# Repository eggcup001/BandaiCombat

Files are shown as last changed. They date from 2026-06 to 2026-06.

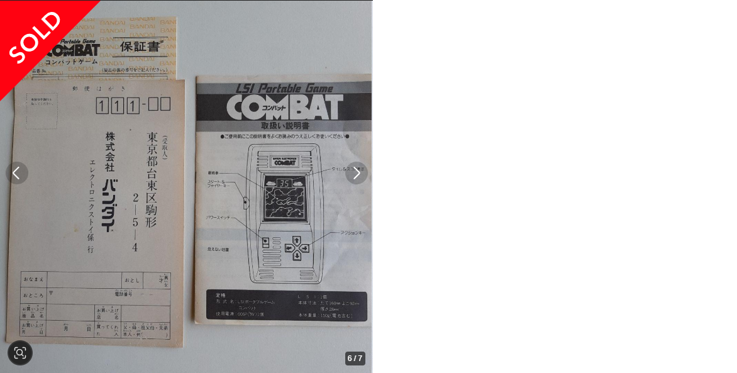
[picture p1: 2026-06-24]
docs/no1/005.png

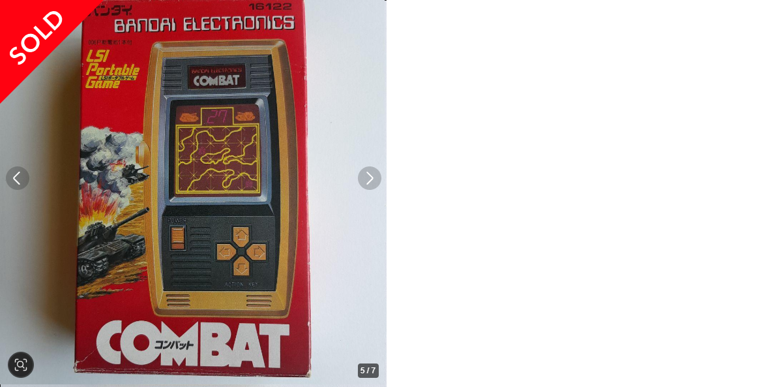
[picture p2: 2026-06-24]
docs/no1/004.png

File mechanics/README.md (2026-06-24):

【ゲーム仕様】
ゲームのカウントは99秒内で自機は10台までで終了。カウントは0から換算され99を超えるとゲームオーバー
5x4のLEDマトリクスに敵機と自機がそれぞれ１台ずつランダムに配置される。また地雷が2～3個配置される。
待機画面は上記で配置された状態で敵機(薄暗い)、自機(明るい)、現在のカウントが表示され、敵機0.5秒間隔くらいで点滅。

Fireボタンでスタート、カウントが1秒ずつ加算される。
上下左右ボタンで自機を移動し、敵の前でFireボタン＋方向で攻撃となる。Fireボタンを押さずに敵と同じマスに入った場合は自機を1台失う。
敵の上下左右又は斜めの、一つ隣に入ると約1秒間隔で敵の攻撃が来る(1回点滅で1攻撃)。
敵の攻撃が連続3回当たると自機を1台失う。自機を移動し隣ではなくなるとヒット回数がリセットされる。

ランダムに配置された地雷の上下左右一つ隣に入ると警告音が鳴る。
地雷を踏むと自機を1台失う。

攻撃が成功した場合は得点が1加算され、次の配置と待機モーションへ移行する。
敵の攻撃や接触、地雷で自機を1台失った場合は、その面の最初の配置にリセットされる(カウンタは増加し続ける)
ゲームオーバーで終了時、得点が表示され、終了。配置は次の面を配置する。スタートで得点を0点へリセットしカウントを0から開始でゲームスタート。

ゲーム進行時はカウントの様な音が鳴り続ける。待機中は無音。自機を失った場合は音が鳴る。
ゲームオーバー時は終了時のメロディーが鳴る。

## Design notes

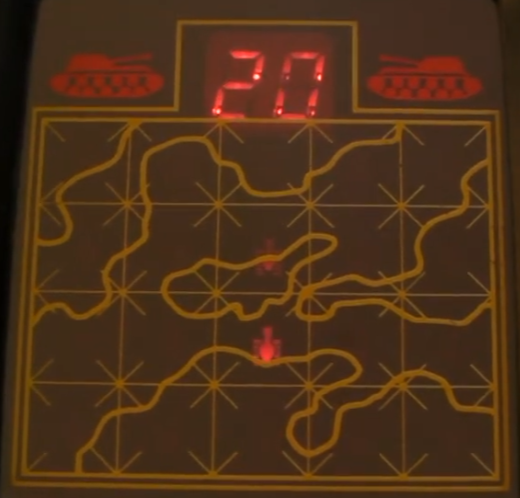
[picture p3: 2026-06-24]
docs/no3/スクリーンショット 2026-06-22 230143.png

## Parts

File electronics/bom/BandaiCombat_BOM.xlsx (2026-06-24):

 | Sourced | Placed | References | Value | Footprint | Quantity
1 |  |  | C2, C3, C4 | 0.1uF | C_Disc_D5.0mm_W2.5mm_P5.00mm | 3
2 |  |  | C1 | 10nF | C_Disc_D5.0mm_W2.5mm_P5.00mm | 1
3 |  |  | C5 | 10uF | CP_Radial_D5.0mm_P2.00mm | 1
4 |  |  | R1, R5 | 10k | R_Axial_DIN0207_L6.3mm_D2.5mm_P7.62mm_Horizontal | 2
5 |  |  | R2, R6 | 1k | R_Axial_DIN0207_L6.3mm_D2.5mm_P7.62mm_Horizontal | 2
6 |  |  | R3 | 2.2k | R_Axial_DIN0207_L6.3mm_D2.5mm_P7.62mm_Horizontal | 1
7 |  |  | R4 | 4.7k | R_Axial_DIN0207_L6.3mm_D2.5mm_P7.62mm_Horizontal | 1
8 |  |  | D00, D01, D02, D03, D10, D11, D12, D13, D20, D21, D22, D23, D30, D31, D32, D33, D40, D41, D42, D43 | LED | LED_D5.0mm | 20
9 |  |  | D4 | 1N4148 | D_DO-35_SOD27_P7.62mm_Horizontal | 1
10 |  |  | U2, U3 | 74HC595 | DIP-16_W7.62mm | 2
11 |  |  | U4, U5 | D168K | D1X8K | 2
12 |  |  | U1 | ATtiny85-20P | DIP-8_W7.62mm | 1
13 |  |  | SW6 | Conn_02x03_Odd_Even | PinHeader_2x03_P2.54mm_Vertical | 1
14 |  |  | Q1, Q2, Q3, Q4, Q5, Q6, Q7 | 2SC1815 | TO-92_Inline | 7
15 |  |  | SW_DOWN1, SW_FIRE1, SW_LEFT1, SW_RIGHT1, SW_UP1 | SW_Push | SW_PUSH_6mm | 5
16 |  |  | RN1, RN2 | 330 | R_Array_Convex_4x0603 | 2
17 |  |  | RN3, RN4 | 4.7k | R_Array_Convex_4x0603 | 2
18 |  |  | 9042_16R1 | Buzzer | MagneticBuzzer_PUI_AT-0927-TT-6-R | 1
19 |  |  | BT1 | Battery | PinHeader_1x02_P2.54mm_Vertical | 1
20 |  |  | RN5 | 100k | R_Array_SIP9 | 1

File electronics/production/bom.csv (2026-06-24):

Designator | Footprint | Quantity | Value | LCSC Part #
9042_16R1 | MagneticBuzzer_PUI_AT-0927-TT-6-R | 1 | Buzzer
BT1 | PinHeader_1x02_P2.54mm_Vertical | 1 | Battery
C1 | C_Disc_D5.0mm_W2.5mm_P5.00mm | 1 | 10nF
C2, C3, C4 | C_Disc_D5.0mm_W2.5mm_P5.00mm | 3 | 0.1uF
C5 | CP_Radial_D5.0mm_P2.00mm | 1 | 10uF
D00, D01, D02, D03, D10, D11, D12, D13, D20, D21, D22, D23, D30, D31, D32, D33, D40, D41, D42, D43 | LED_D5.0mm | 20 | LED
D4 | D_DO-35_SOD27_P7.62mm_Horizontal | 1 | 1N4148
Q1, Q2, Q3, Q4, Q5, Q6, Q7 | TO-92_Inline | 7 | 2SC1815
R1, R5 | R_Axial_DIN0207_L6.3mm_D2.5mm_P7.62mm_Horizontal | 2 | 10k
R2, R6 | R_Axial_DIN0207_L6.3mm_D2.5mm_P7.62mm_Horizontal | 2 | 1k
R3 | R_Axial_DIN0207_L6.3mm_D2.5mm_P7.62mm_Horizontal | 1 | 2.2k
R4 | R_Axial_DIN0207_L6.3mm_D2.5mm_P7.62mm_Horizontal | 1 | 4.7k
RN1, RN2 | R_Array_Convex_4x0603 | 2 | 330
RN3, RN4 | R_Array_Convex_4x0603 | 2 | 4.7k
RN5 | R_Array_SIP9 | 1 | 100k
SW6 | PinHeader_2x03_P2.54mm_Vertical | 1 | Conn_02x03_Odd_Even
SW_DOWN1, SW_FIRE1, SW_LEFT1, SW_RIGHT1, SW_UP1 | SW_PUSH_6mm | 5 | SW_Push
U1 | DIP-8_W7.62mm | 1 | ATtiny85-20P
U2, U3 | DIP-16_W7.62mm | 2 | 74HC595
U4, U5 | D1X8K | 2 | D168K

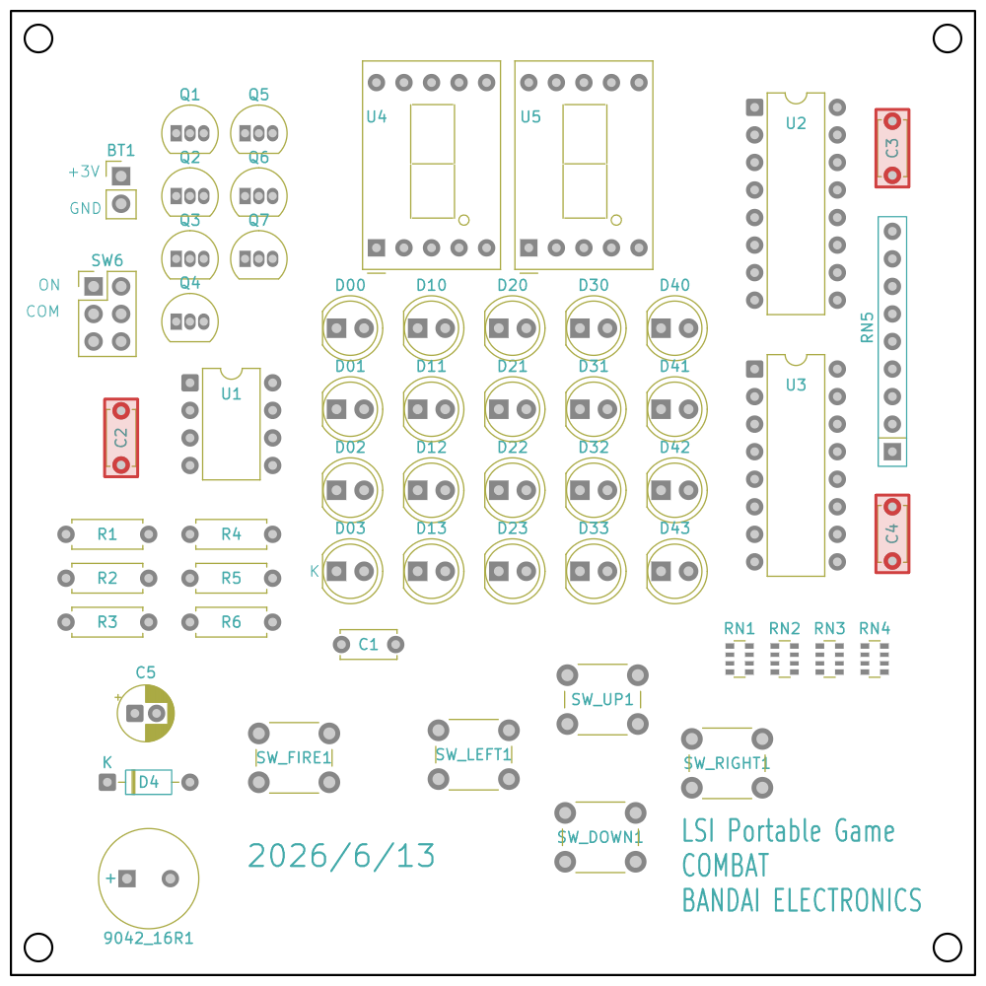
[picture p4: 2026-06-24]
electronics/bom/BandaiCombat.F.png

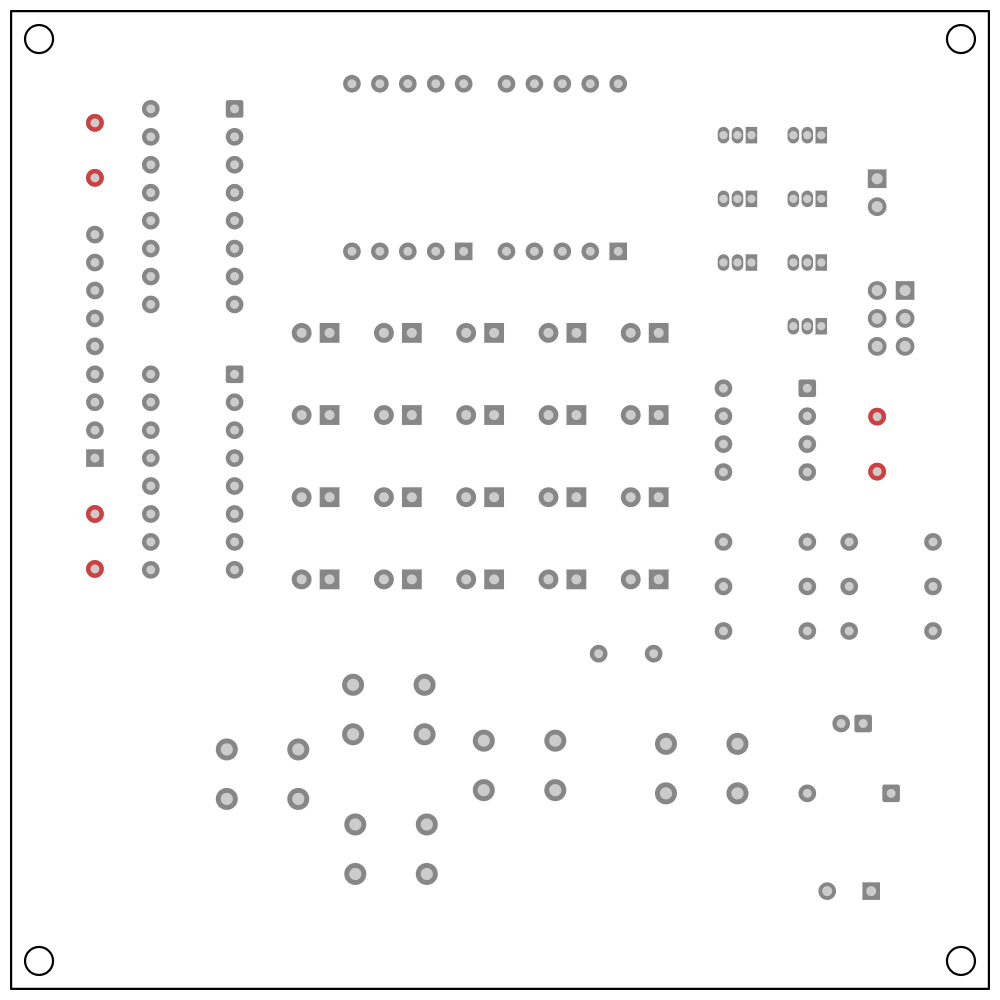
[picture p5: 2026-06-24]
electronics/bom/BandaiCombat.B.png

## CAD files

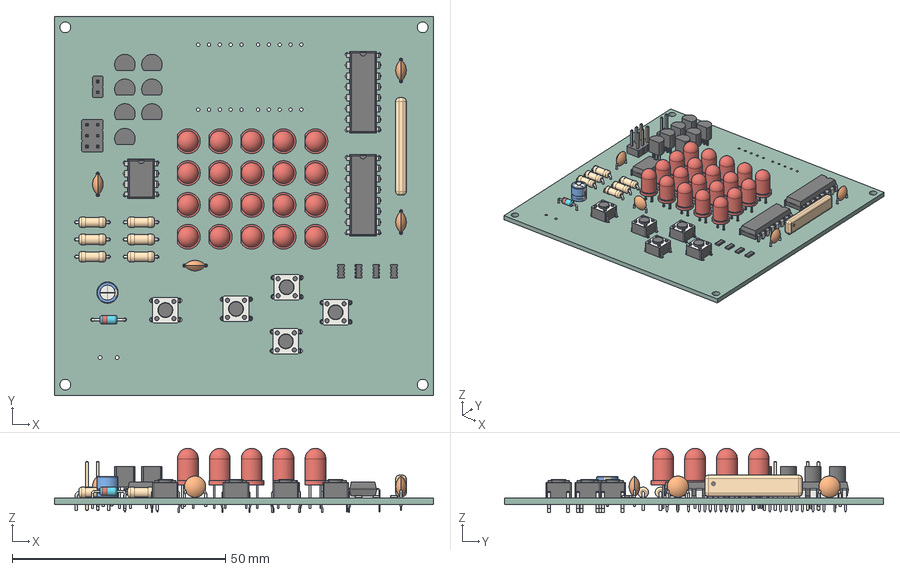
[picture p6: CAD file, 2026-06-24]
electronics/doc/基板2.step
88.9 x 88.9 x 15.1 mm
R_Array_Convex_4x0603 x 4
R_Axial_DIN0207_L6.3mm_D2.5mm_P7.62mm_Horizontal x 6
LED_D5.0mm x 20
SW_PUSH_6mm x 5
TO-92_Inline x 7
C_Disc_D5.0mm_W2.5mm_P5.00mm x 4
D_DO-35_SOD27_P7.62mm_Horizontal
CP_Radial_D5.0mm_P2.00mm
PinHeader_2x03_P2.54mm_Vertical
DIP-8_W7.62mm
R_Array_SIP9
DIP-16_W7.62mm x 2
PinHeader_1x02_P2.54mm_Vertical
BandaiCombat_PCB

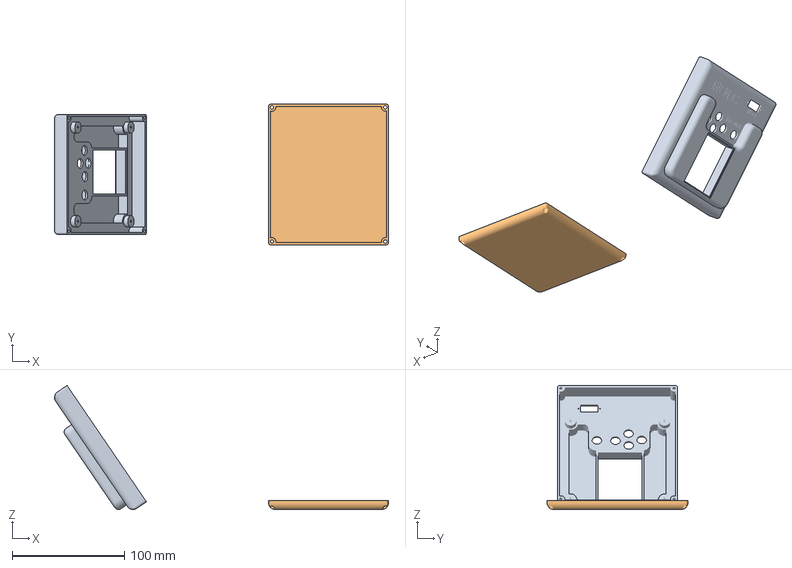
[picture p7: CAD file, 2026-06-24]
mechanics/bambu/combat_box.3mf
298.1 x 125.7 x 110.7 mm
top
bottom

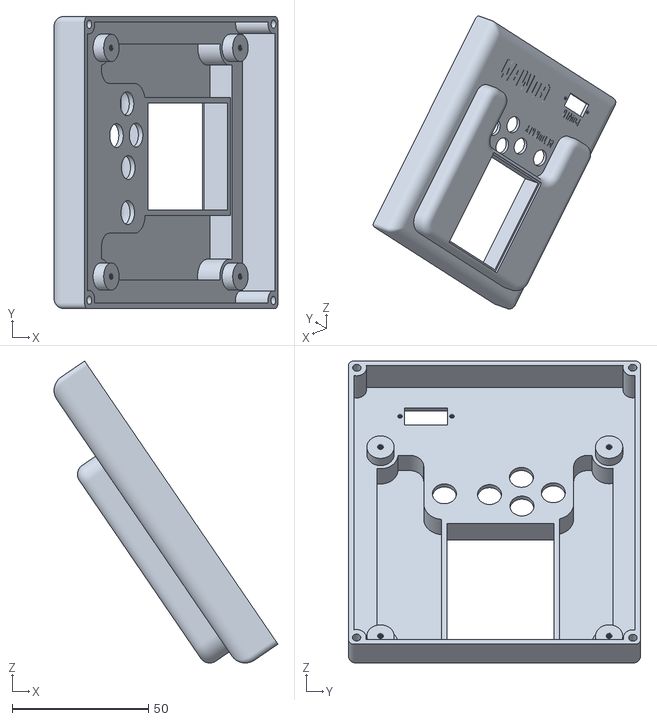
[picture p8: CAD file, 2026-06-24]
mechanics/stl/top.stl
82.1 x 107.1 x 110.7

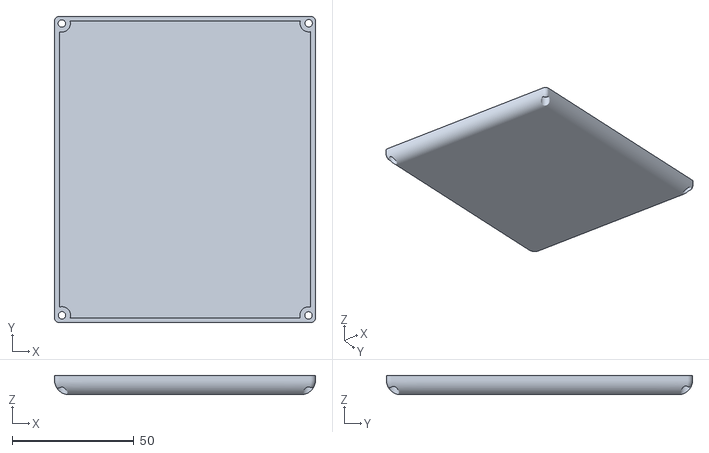
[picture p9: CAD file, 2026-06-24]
mechanics/stl/bottom.stl
107.1 x 125.7 x 8.00

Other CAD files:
mechanics/fusion/combat_box.f3d

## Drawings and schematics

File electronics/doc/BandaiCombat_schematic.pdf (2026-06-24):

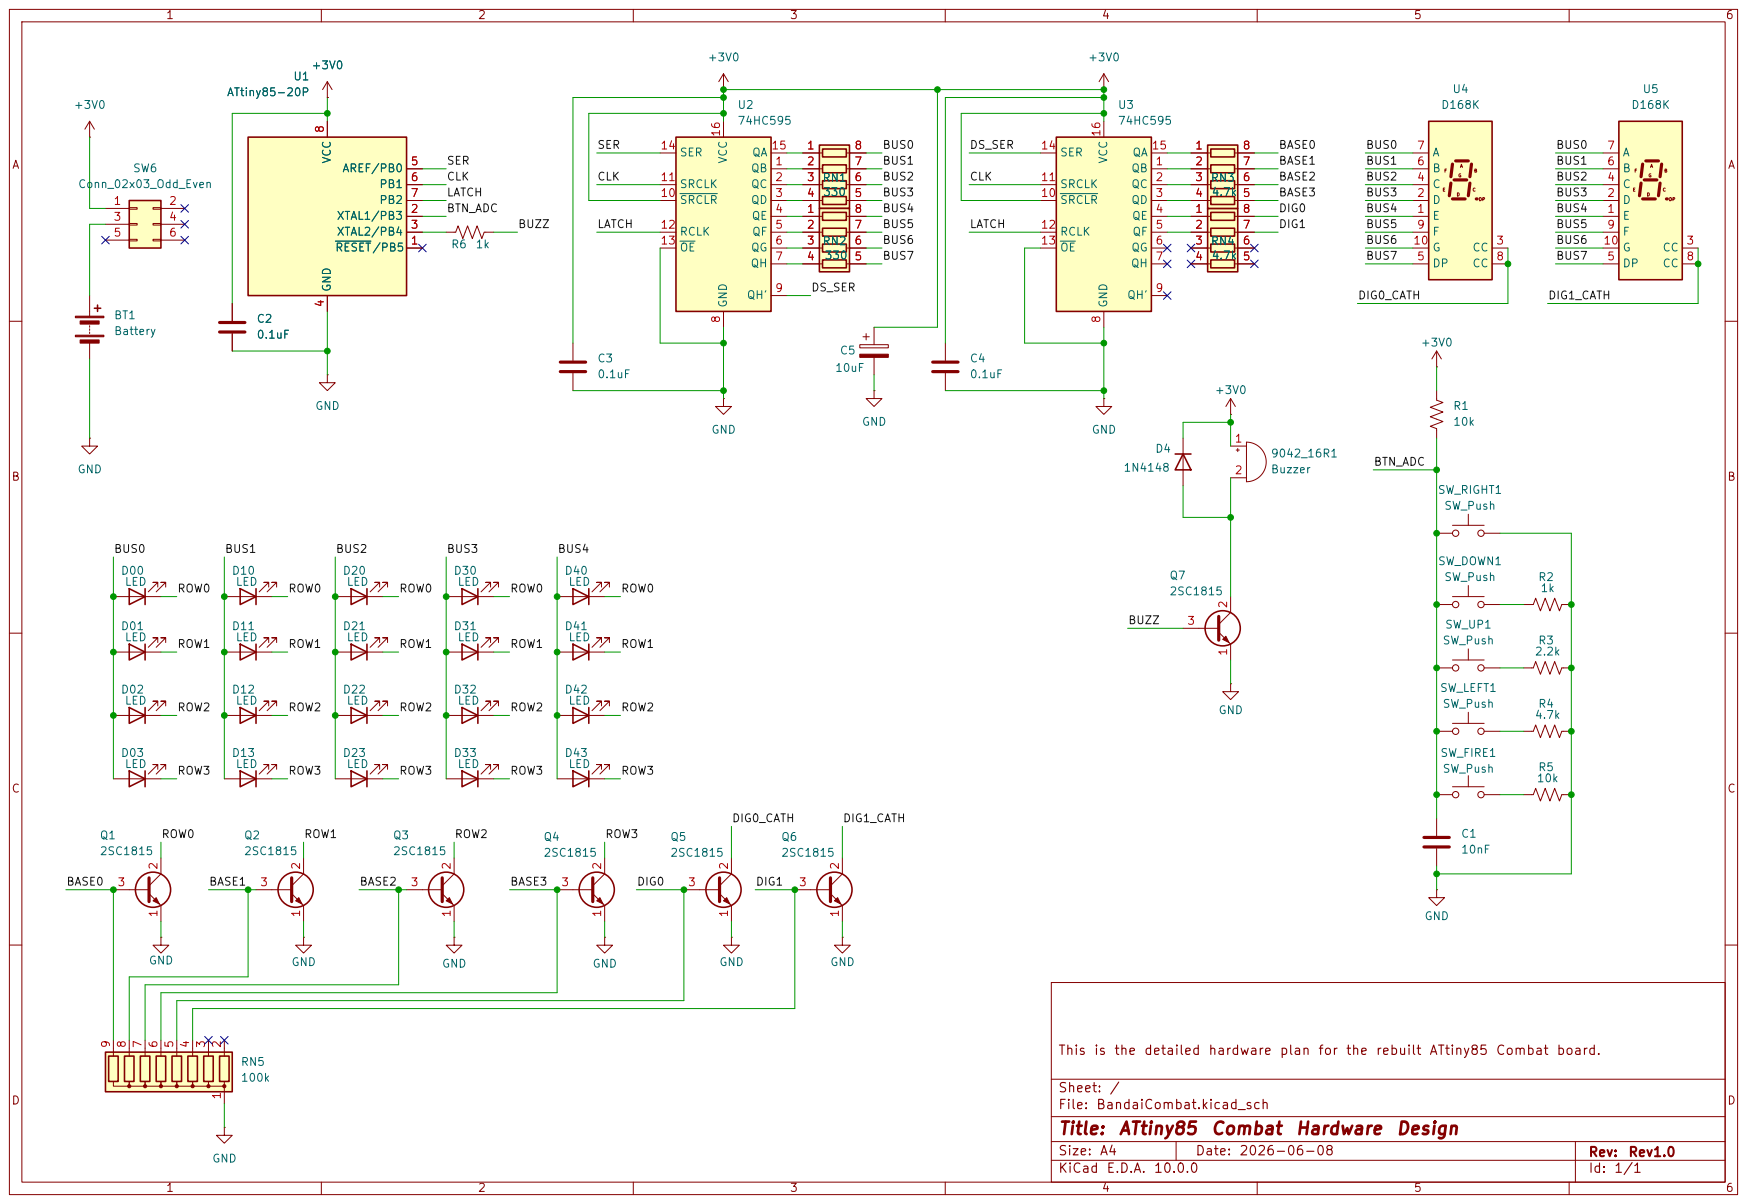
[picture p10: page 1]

SRCLR 10 SRCLK 11 RCLK 12 OE 13 | 330

D01 | LED | LED

This is the detailed hardware plan for the rebuilt ATtiny85 Combat board. D02

LED | LED | D22 LED

LED | D13 LED | D23 LED

Sheet: /
D Date: 2026-06-08 KiCad E.D.A. 10.0.0
File: BandaiCombat.kicad_sch
Title: ATtiny85 Combat Hardware Design

Size: A4 | Rev: Rev1.0

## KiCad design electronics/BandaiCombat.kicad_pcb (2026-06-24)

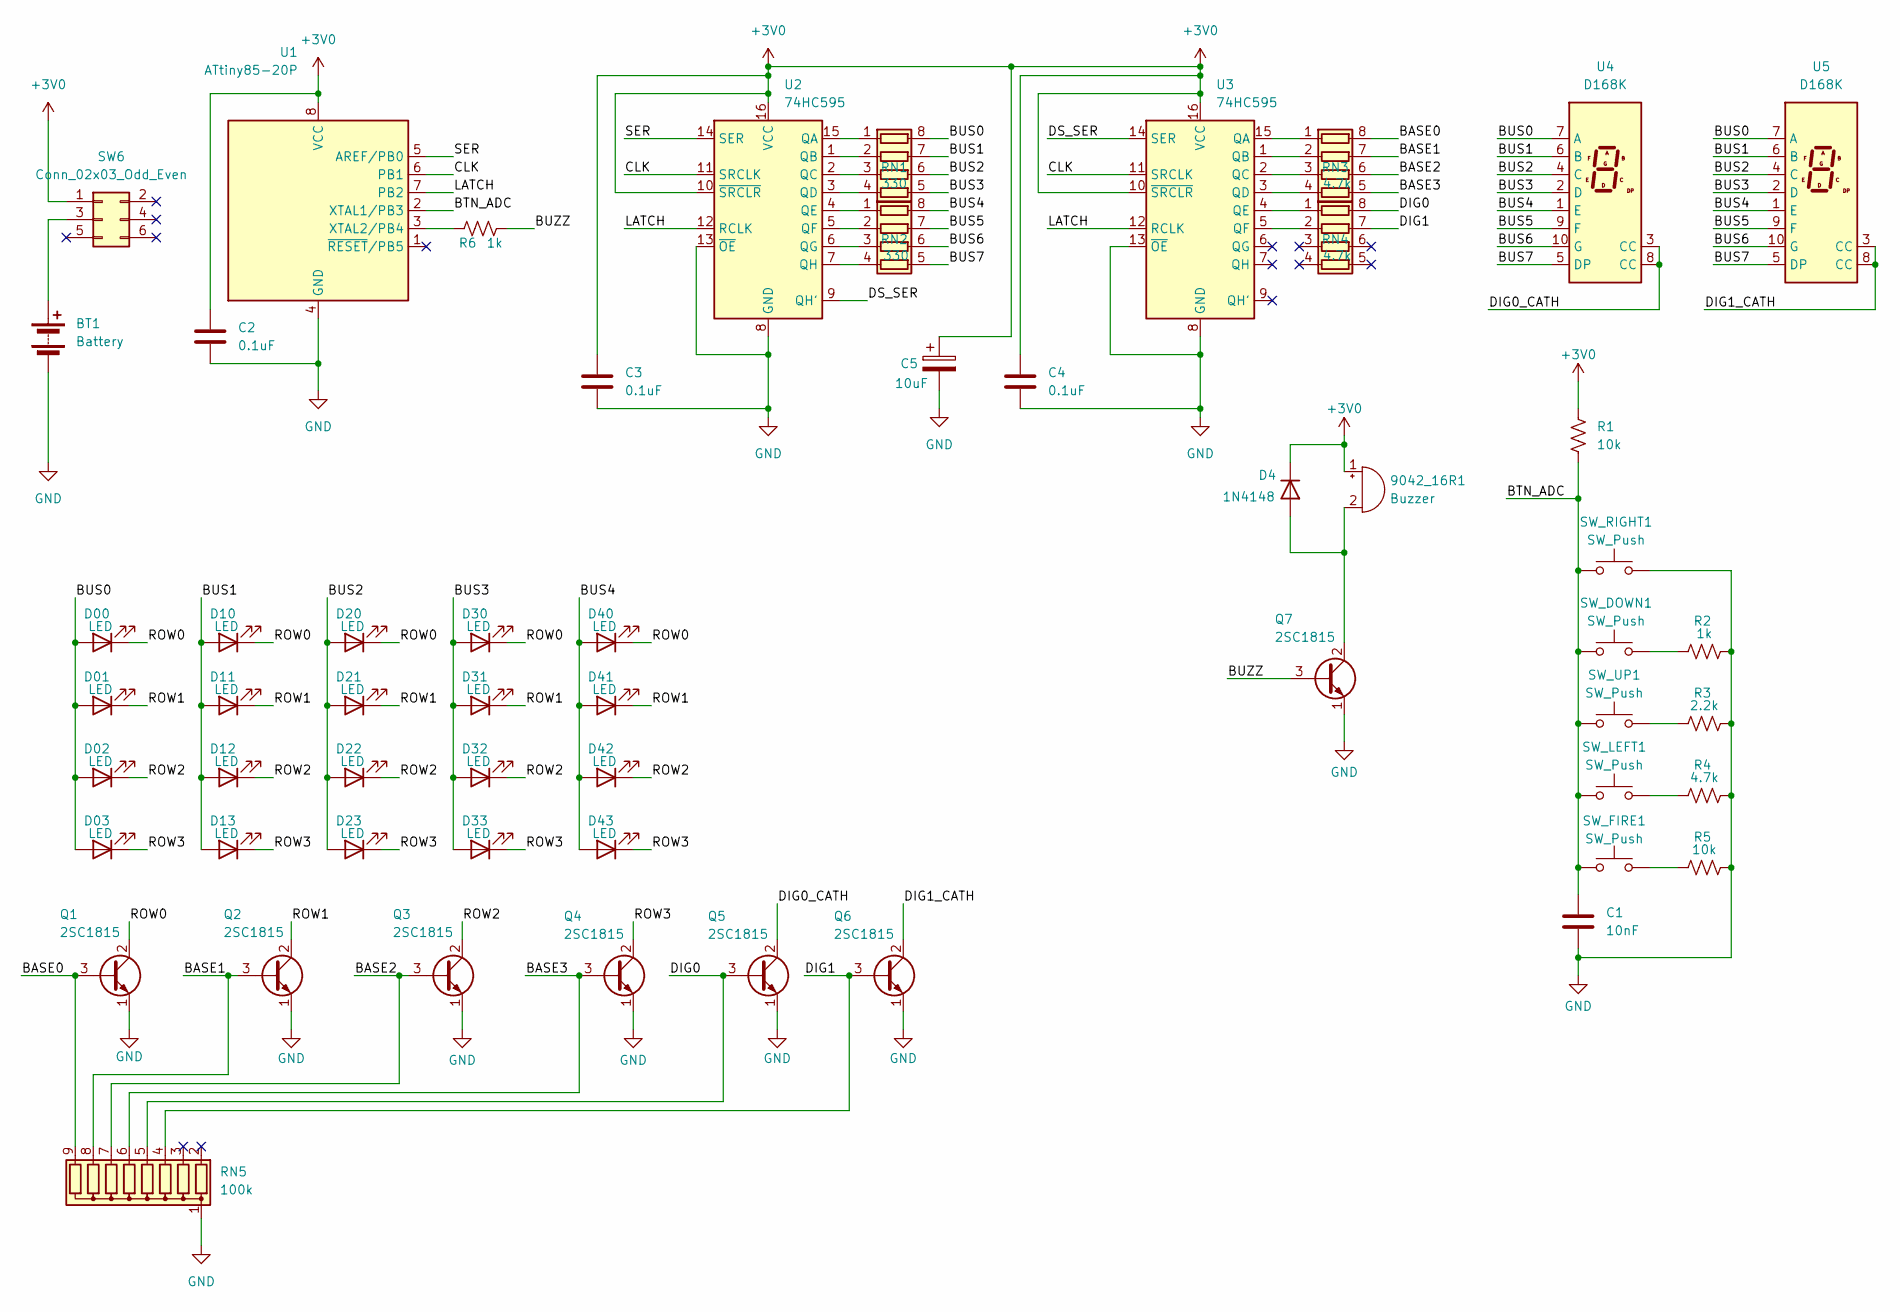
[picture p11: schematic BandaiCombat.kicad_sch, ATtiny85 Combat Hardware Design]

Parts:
9042_16R1: Buzzer; MagneticBuzzer_PUI_AT-0927-TT-6-R
BT1: Battery; PinHeader_1x02_P2.54mm_Vertical
C1: 10nF; C_Disc_D5.0mm_W2.5mm_P5.00mm
C2, C3, C4: 0.1uF; C_Disc_D5.0mm_W2.5mm_P5.00mm
C5: 10uF; CP_Radial_D5.0mm_P2.00mm
D00, D01, D02, D03, D10, D11, D12, D13, D20, D21, D22, D23, D30, D31, D32, D33, D40, D41, D42, D43: LED; LED_D5.0mm
D4: 1N4148; D_DO-35_SOD27_P7.62mm_Horizontal
Q1, Q2, Q3, Q4, Q5, Q6, Q7: 2SC1815; TO-92_Inline
R1, R5: 10k; R_Axial_DIN0207_L6.3mm_D2.5mm_P7.62mm_Horizontal
R2, R6: 1k; R_Axial_DIN0207_L6.3mm_D2.5mm_P7.62mm_Horizontal
R3: 2.2k; R_Axial_DIN0207_L6.3mm_D2.5mm_P7.62mm_Horizontal
R4: 4.7k; R_Axial_DIN0207_L6.3mm_D2.5mm_P7.62mm_Horizontal
RN1, RN2: 330; R_Array_Convex_4x0603
RN3, RN4: 4.7k; R_Array_Convex_4x0603
RN5: 100k; R_Array_SIP9
SW6: Conn_02x03_Odd_Even; PinHeader_2x03_P2.54mm_Vertical
SW_DOWN1: SW_Push; SW_PUSH_6mm
SW_FIRE1: SW_Push; SW_PUSH_6mm
SW_LEFT1: SW_Push; SW_PUSH_6mm
SW_RIGHT1: SW_Push; SW_PUSH_6mm
SW_UP1: SW_Push; SW_PUSH_6mm
U1: ATtiny85-20P; DIP-8_W7.62mm
U2, U3: 74HC595; DIP-16_W7.62mm
U4, U5: D168K; D1X8K

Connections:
+3V0: 9042_16R1.1 (+), C2.1, C3.1, C4.1, C5.1, D4.1 (K), R1.1, SW6.1, U1.8 (VCC), U2.10 (~SRCLR), U2.16 (VCC), U3.10 (~SRCLR), U3.16 (VCC)
/BASE0: Q1.3 (B), RN3.8 (R1.2), RN5.9 (R8)
/BASE1: Q2.3 (B), RN3.7 (R2.2), RN5.8 (R7)
/BASE2: Q3.3 (B), RN3.6 (R3.2), RN5.7 (R6)
/BASE3: Q4.3 (B), RN3.5 (R4.2), RN5.6 (R5)
/BTN_ADC: C1.1, R1.2, SW_DOWN1.1, SW_FIRE1.1, SW_LEFT1.1, SW_RIGHT1.1, SW_UP1.1, U1.2 (XTAL1/PB3)
/BUS0: D00.2 (A), D01.2 (A), D02.2 (A), D03.2 (A), RN1.8 (R1.2), U4.7 (A), U5.7 (A)
/BUS1: D10.2 (A), D11.2 (A), D12.2 (A), D13.2 (A), RN1.7 (R2.2), U4.6 (B), U5.6 (B)
/BUS2: D20.2 (A), D21.2 (A), D22.2 (A), D23.2 (A), RN1.6 (R3.2), U4.4 (C), U5.4 (C)
/BUS3: D30.2 (A), D31.2 (A), D32.2 (A), D33.2 (A), RN1.5 (R4.2), U4.2 (D), U5.2 (D)
/BUS4: D40.2 (A), D41.2 (A), D42.2 (A), D43.2 (A), RN2.8 (R1.2), U4.1 (E), U5.1 (E)
/BUS5: RN2.7 (R2.2), U4.9 (F), U5.9 (F)
/BUS6: RN2.6 (R3.2), U4.10 (G), U5.10 (G)
/BUS7: RN2.5 (R4.2), U4.5 (DP), U5.5 (DP)
/BUZZ: Q7.3 (B), R6.2
/CLK: U1.6 (PB1), U2.11 (SRCLK), U3.11 (SRCLK)
/DIG0: Q5.3 (B), RN4.8 (R1.2), RN5.5 (R4)
/DIG0_CATH: Q5.2 (C), U4.3 (CC), U4.8 (CC)
/DIG1: Q6.3 (B), RN4.7 (R2.2), RN5.4 (R3)
/DIG1_CATH: Q6.2 (C), U5.3 (CC), U5.8 (CC)
/DS_SER: U2.9 (QH'), U3.14 (SER)
/LATCH: U1.7 (PB2), U2.12 (RCLK), U3.12 (RCLK)
/ROW0: D00.1 (K), D10.1 (K), D20.1 (K), D30.1 (K), D40.1 (K), Q1.2 (C)
/ROW1: D01.1 (K), D11.1 (K), D21.1 (K), D31.1 (K), D41.1 (K), Q2.2 (C)
/ROW2: D02.1 (K), D12.1 (K), D22.1 (K), D32.1 (K), D42.1 (K), Q3.2 (C)
/ROW3: D03.1 (K), D13.1 (K), D23.1 (K), D33.1 (K), D43.1 (K), Q4.2 (C)
/SER: U1.5 (AREF/PB0), U2.14 (SER)
GND: BT1.2 (-), C1.2, C2.2, C3.2, C4.2, C5.2, Q1.1 (E), Q2.1 (E), Q3.1 (E), Q4.1 (E), Q5.1 (E), Q6.1 (E), Q7.1 (E), R2.2, R3.2, R4.2, R5.2, RN5.1 (common), SW_RIGHT1.2, U1.4 (GND), U2.8 (GND), U2.13 (~OE), U3.8 (GND), U3.13 (~OE)
unnamed: 9042_16R1.2 (-), D4.2 (A), Q7.2 (C)
unnamed: BT1.1 (+), SW6.3
unnamed: R2.1, SW_DOWN1.2
unnamed: R3.1, SW_UP1.2
unnamed: R4.1, SW_LEFT1.2
unnamed: R5.1, SW_FIRE1.2
unnamed: RN1.1 (R1.1), U2.15 (QA)
unnamed: RN1.2 (R2.1), U2.1 (QB)
unnamed: RN1.3 (R3.1), U2.2 (QC)
unnamed: RN1.4 (R4.1), U2.3 (QD)
unnamed: RN2.1 (R1.1), U2.4 (QE)
unnamed: RN2.2 (R2.1), U2.5 (QF)
unnamed: RN2.3 (R3.1), U2.6 (QG)
unnamed: RN2.4 (R4.1), U2.7 (QH)
unnamed: RN3.1 (R1.1), U3.15 (QA)
unnamed: RN3.2 (R2.1), U3.1 (QB)
unnamed: RN3.3 (R3.1), U3.2 (QC)
unnamed: RN3.4 (R4.1), U3.3 (QD)
unnamed: RN4.1 (R1.1), U3.4 (QE)
unnamed: RN4.2 (R2.1), U3.5 (QF)
unnamed: R6.1, U1.3 (XTAL2/PB4)

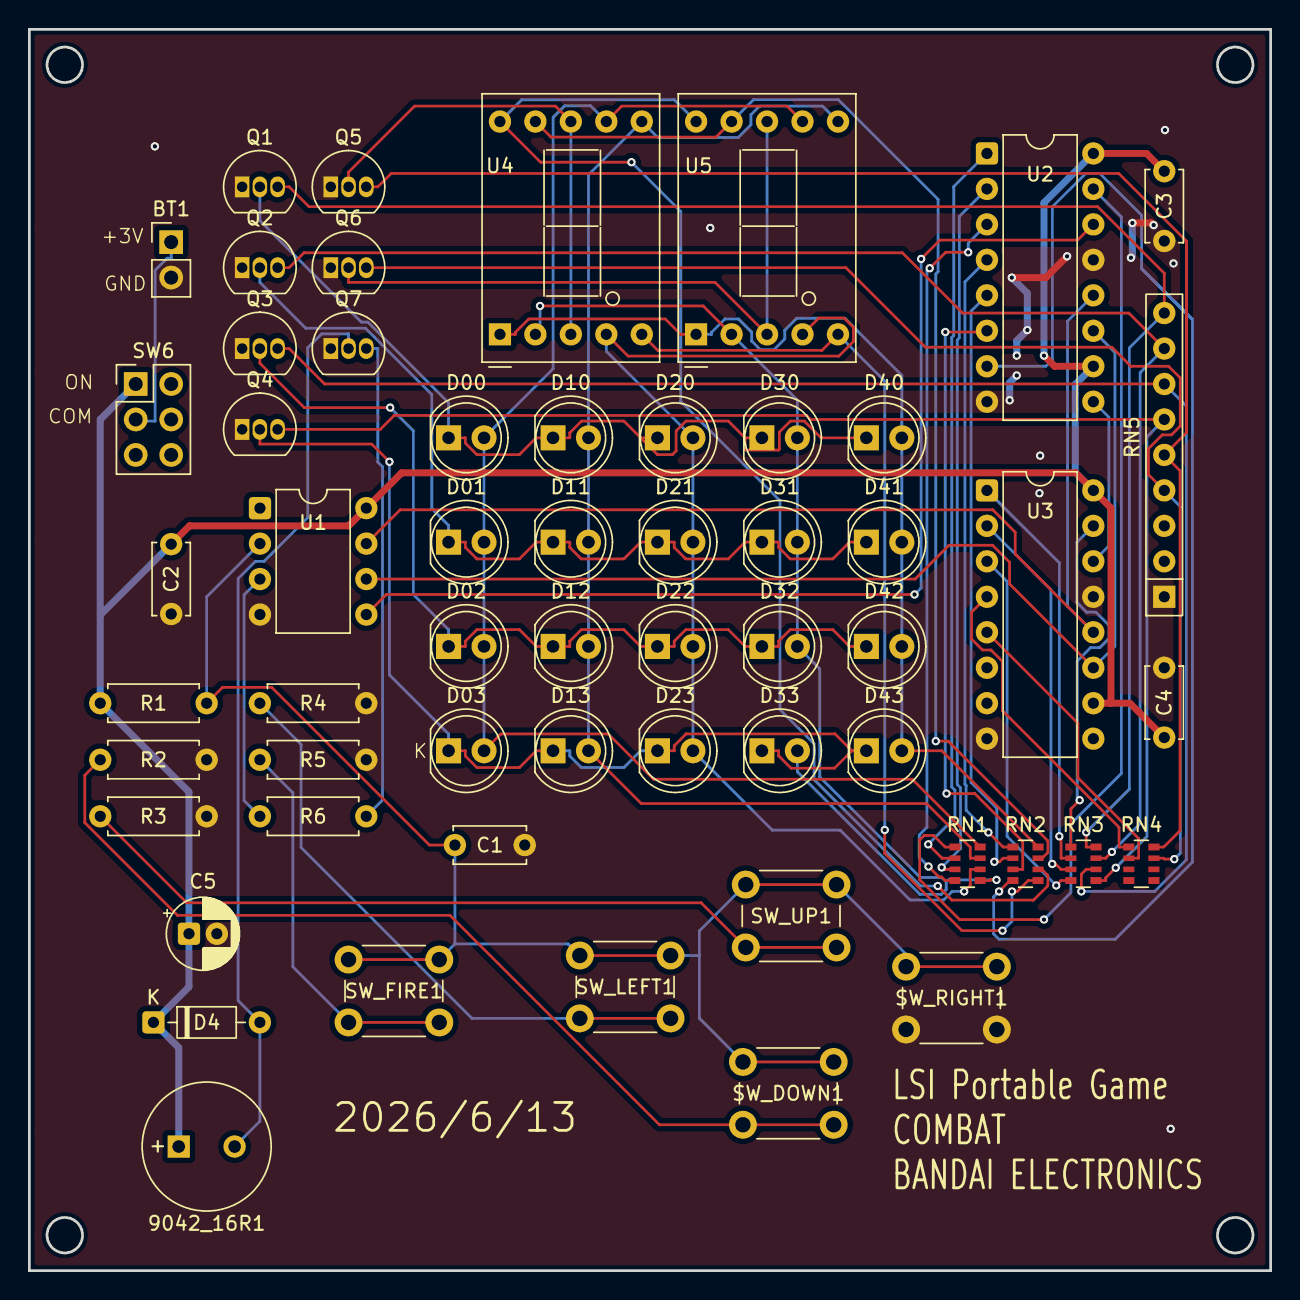
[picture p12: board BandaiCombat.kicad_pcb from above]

Board: 2 copper layers, 88.9 x 88.9 mm, 57 parts (0 on the bottom side), 49 nets.
